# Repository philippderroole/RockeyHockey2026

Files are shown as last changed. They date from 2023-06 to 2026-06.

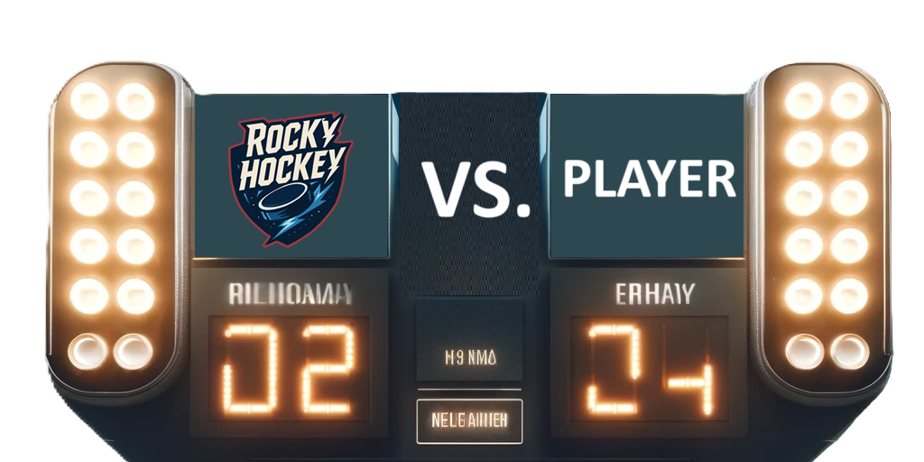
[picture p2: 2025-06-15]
UIServer/resources/imgs/Spielstandanzeige_EM.png

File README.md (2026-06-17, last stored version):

# Rocky-Hockey

## Rust Headless Rewrite

The UI-free Rust controller is available in [rust-controller](rust-controller).

- Entry point: [rust-controller/src/main.rs](rust-controller/src/main.rs)
- Runtime loop: [rust-controller/src/app.rs](rust-controller/src/app.rs)
- Strategy: [rust-controller/src/strategy.rs](rust-controller/src/strategy.rs)
- Camera UDP input: [rust-controller/src/camera.rs](rust-controller/src/camera.rs)
- GRBL stepper output: [rust-controller/src/stepper.rs](rust-controller/src/stepper.rs)

Use [rust-controller/README.md](rust-controller/README.md) for build and run instructions.

## Setup Python venv for VSCode

The file `.vscode/tasks.json` defines a task to set up a python virtual environment (`venv`) in Visual Studio Code. The task can be run by clicking *"Terminal"* -> *"Run Task"* -> *"Build Python Env"*.

- Source for Hockey Image: https://www.svgrepo.com/svg/92168/air-hockey

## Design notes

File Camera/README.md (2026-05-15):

# Rockey Hockey Camera

## Voraussetzungen
- Rust (stable) — Rust und Cargo: https://rustup.rs
- OpenCV und die Entwicklungsheaders
	- Debian: `sudo apt install libopencv-dev pkg-config`
	- macOS: `brew install opencv` (oder über Homebrew-Links)
- Für Cross-Compilation: Docker (nur für das mitgelieferte Script)

## Schnellstart (Entwicklung)

Im Projektordner:

```bash
cargo run -- --web-ui --target-output 0.0.0.0:5005
```

- `--web-ui` startet den integrierten Webserver zur Konfiguration der Detektionsziele.
- `--target-output <ip:port>` bindet eine UDP-Interface, an das sich ein Client mit einem Subscribe-Paket anmelden kann. Danach sendet der Detector die Zielpositionen an diesen Client.

Weitere Optionen sehen Sie mit:

```bash
cargo run -- --help
```

## Cross-Compilation für Raspberry Pi (aarch64)

Das Repository enthält ein Hilfs-Skript zur Cross-Compilation mittels Docker.

1. Stellen Sie sicher, dass Docker installiert und lauffähig ist.
2. Prüfen Sie, dass das Docker-Image im `Dockerfile` mit dem Raspberry Pi kompatibel ist.
3. Führen Sie das Script aus:

```bash
./aarch64-cross.sh
```

Nach erfolgreichem Build liegt die Binary unter:

- `target/aarch64-unknown-linux-gnu/release/rockey_hockey`

Kopieren Sie diese Datei auf Ihr Gerät (z. B. mit `scp`) und führen Sie sie dort aus.

## Konfiguration / Web-UI

Die Web-UI dient zur Auswahl und Feinabstimmung der Detektionsziele. Falls Sie `--web-ui` verwenden, wird ein lokaler Webserver gestartet; die genaue URL wird beim Start geloggt.

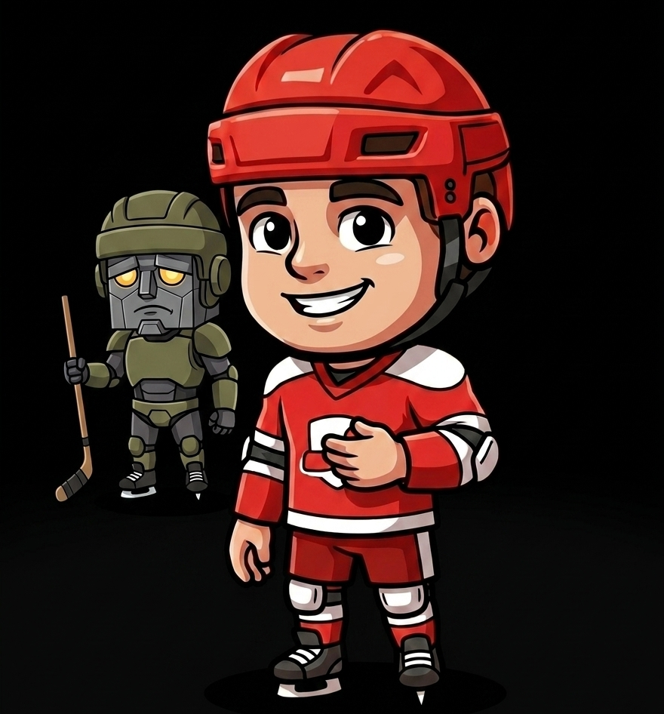
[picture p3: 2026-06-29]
UIServer/resources/imgs/WinningPlayer.png

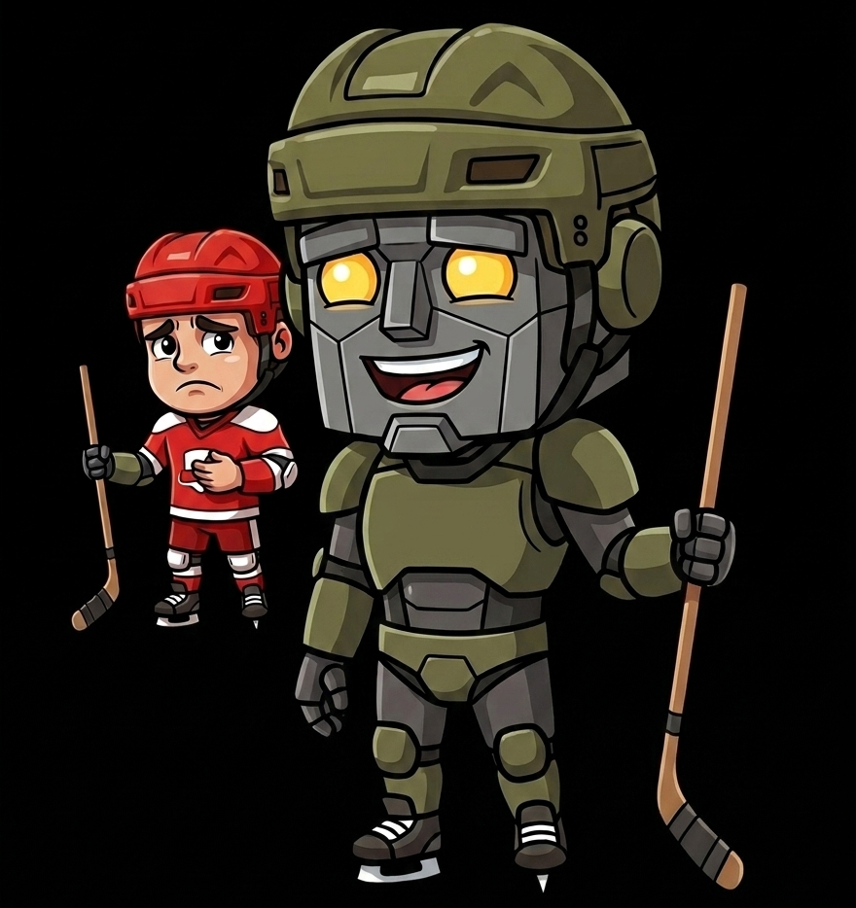
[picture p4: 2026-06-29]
UIServer/resources/imgs/WinningBot.png

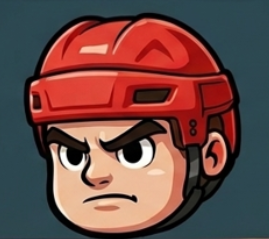
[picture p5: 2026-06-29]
UIServer/resources/imgs/Kopf_des_Spielers.png

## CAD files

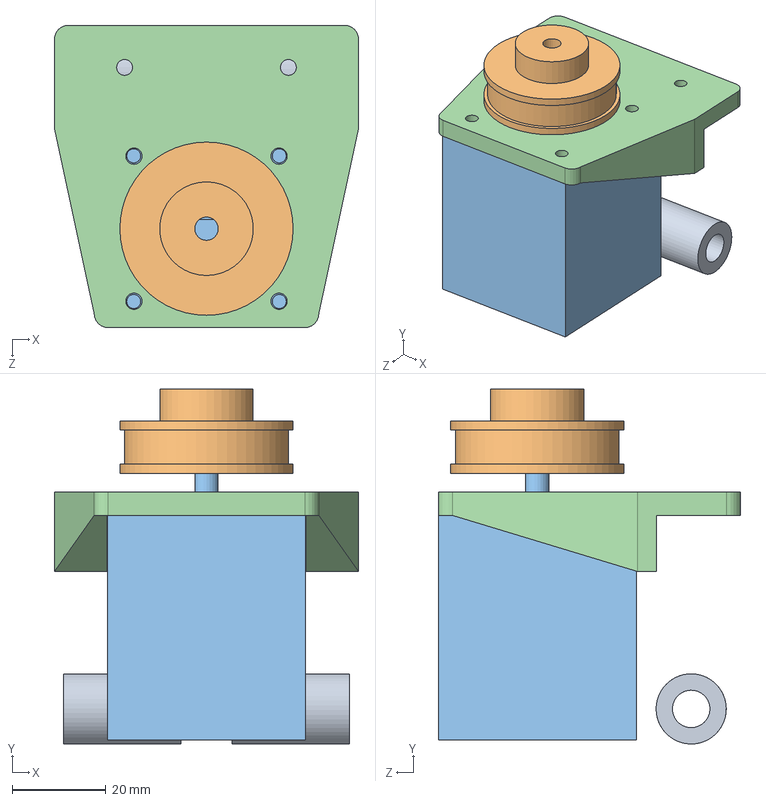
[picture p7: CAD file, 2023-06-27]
CAD/Solidworks/RH_Baugr_Y_Carriage.SLDASM
65.0 x 75.8 x 64.6 mm
RH_Y_Carriage_Motor_Mount
RH_Nema17_Motor
RH_35mm_Riemenscheibe
RH_Bushing_8mm_15mm x 2

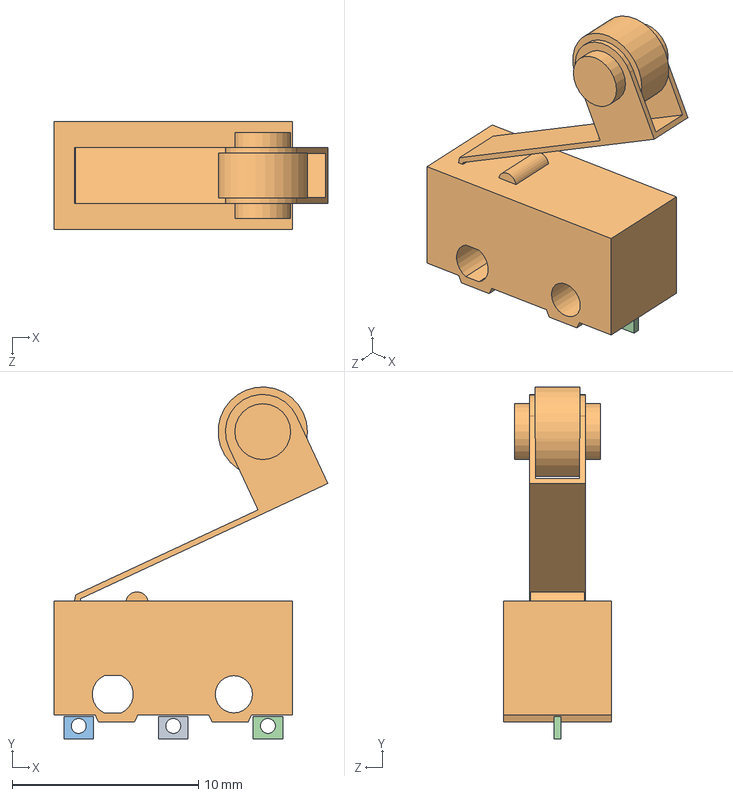
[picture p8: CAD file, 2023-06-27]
CAD/Solidworks/RH_d2f-01fl2-d.SLDASM
14.7 x 18.9 x 5.80 mm
RH_d2f-01fl2-d_01
RH_d2f-01fl2-d_02
RH_d2f-01fl2-d_03
RH_d2f-01fl2-d_04

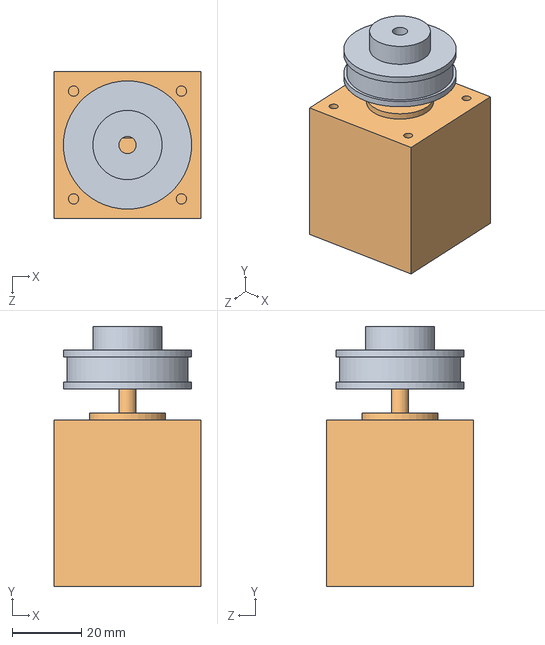
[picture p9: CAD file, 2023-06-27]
CAD/Solidworks/RH_Baugr_Motor_with_90_bracketSLDASM.SLDASM
42.3 x 75.0 x 42.3 mm
RH_Nema17_Motor
RH_35mm_Riemenscheibe

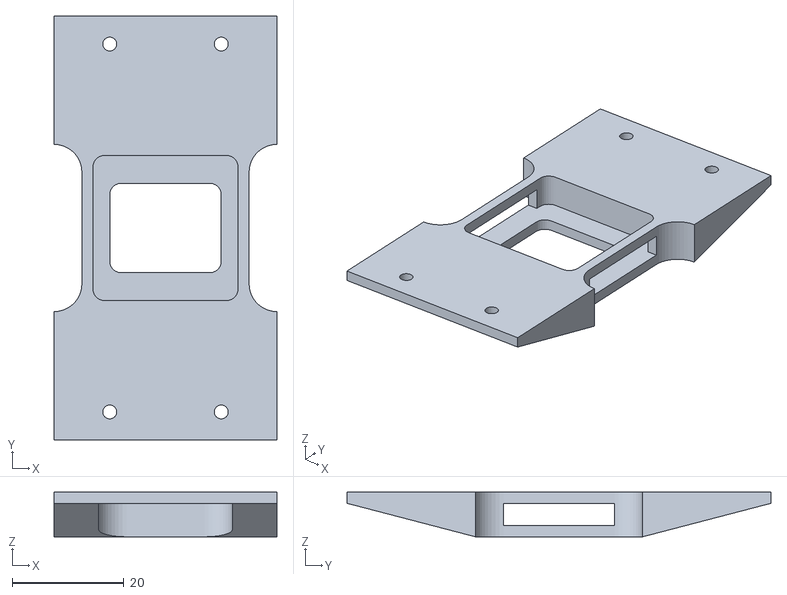
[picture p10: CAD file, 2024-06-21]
CAD/STL/Balken_Halterung_unten.stl
40.0 x 76.0 x 8.00

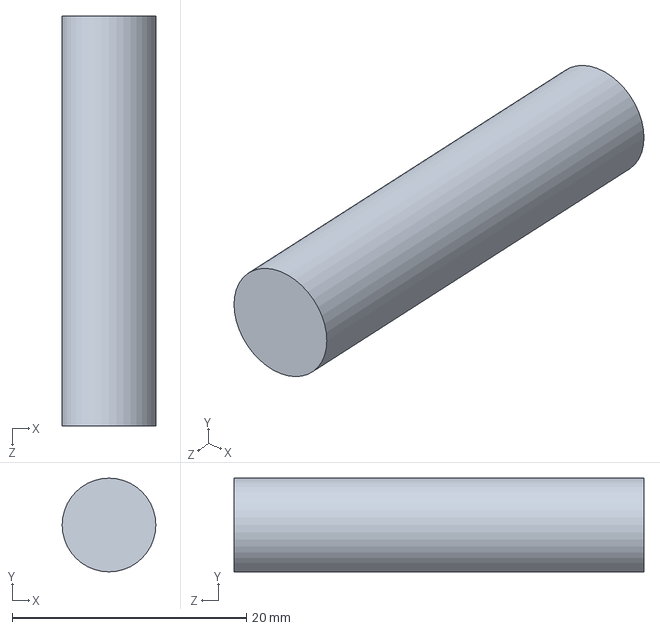
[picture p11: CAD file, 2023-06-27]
CAD/Solidworks/RH_Rail_8mm_35mm.SLDPRT
8.00 x 8.00 x 35.0 mm

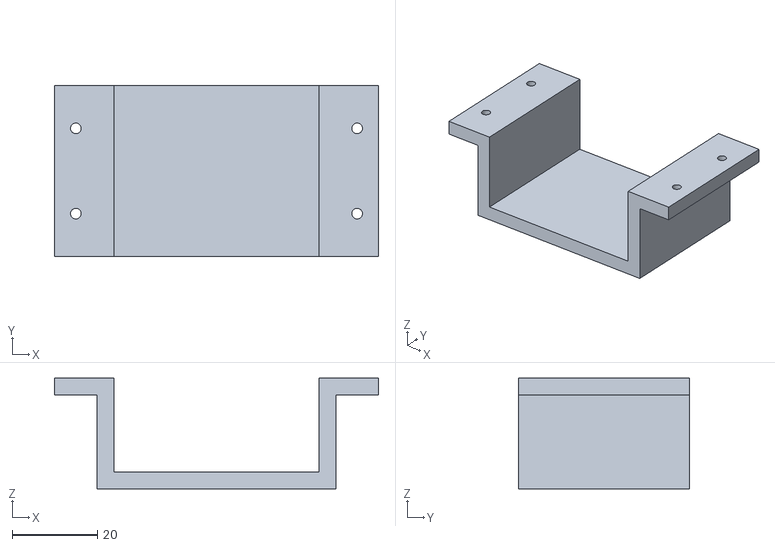
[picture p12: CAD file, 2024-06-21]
CAD/STL/Balken_Halterung_oben.stl
76.0 x 40.0 x 26.0

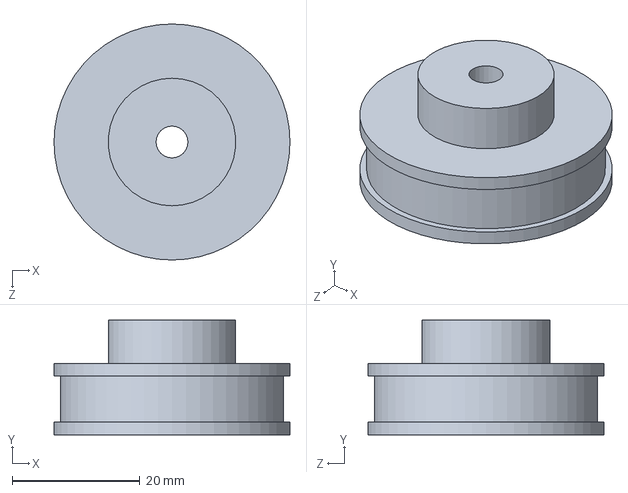
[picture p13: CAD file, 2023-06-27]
CAD/Solidworks/RH_35mm_Riemenscheibe.SLDPRT
37.0 x 18.0 x 37.0 mm

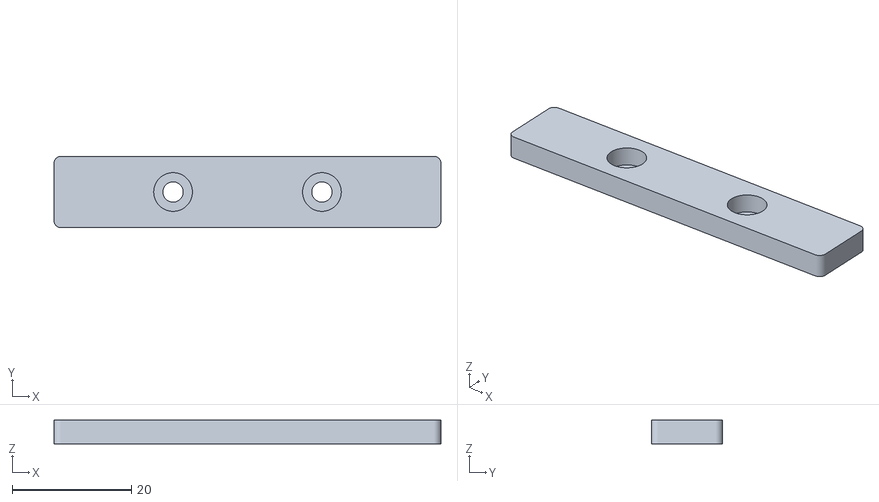
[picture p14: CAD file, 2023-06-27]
CAD/STL/Y_Carriage_Rail_Plate.STL
65.0 x 12.0 x 4.00

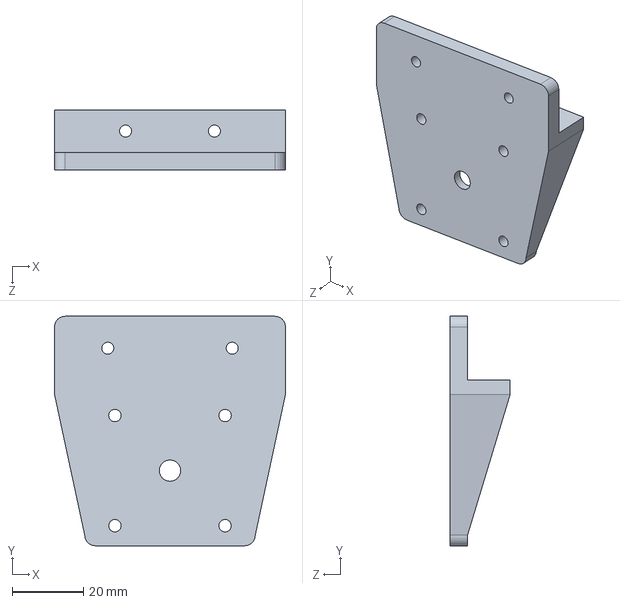
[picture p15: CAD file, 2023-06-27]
CAD/Solidworks/RH_Y_Carriage_Motor_Mount.SLDPRT
65.0 x 64.6 x 17.0 mm

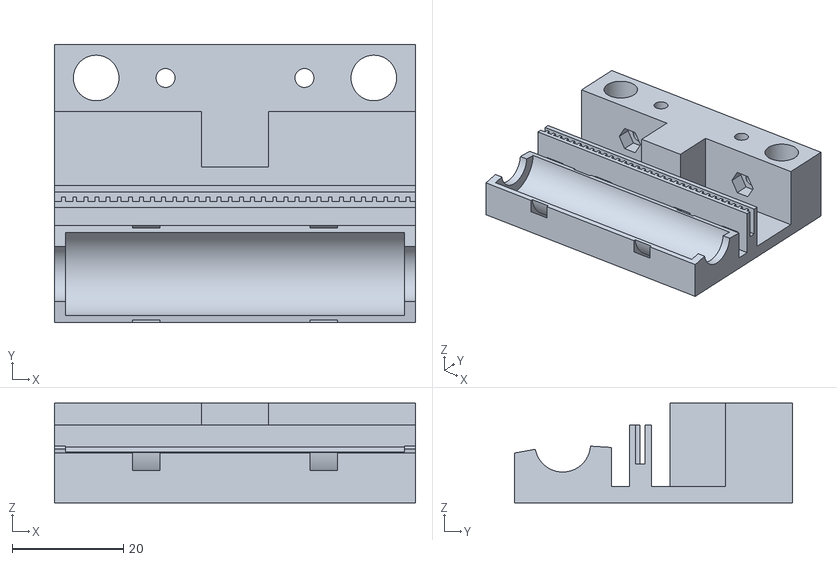
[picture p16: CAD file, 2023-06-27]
CAD/STL/Y_Carriage.STL
65.0 x 50.0 x 18.0

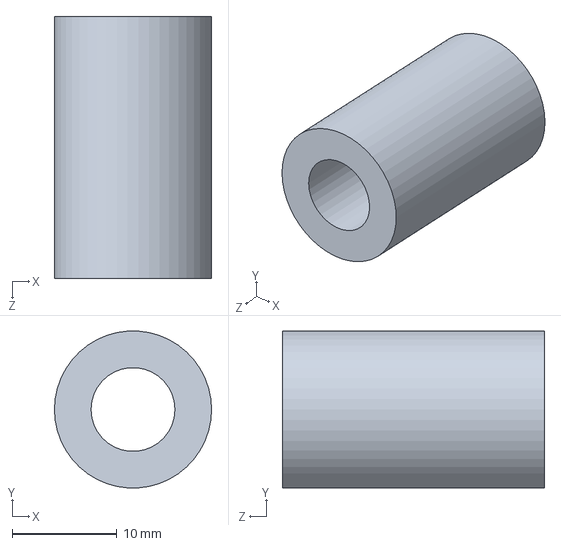
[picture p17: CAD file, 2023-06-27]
CAD/Solidworks/RH_Bushing_8mm_15mm.SLDPRT
15.0 x 15.0 x 25.0 mm

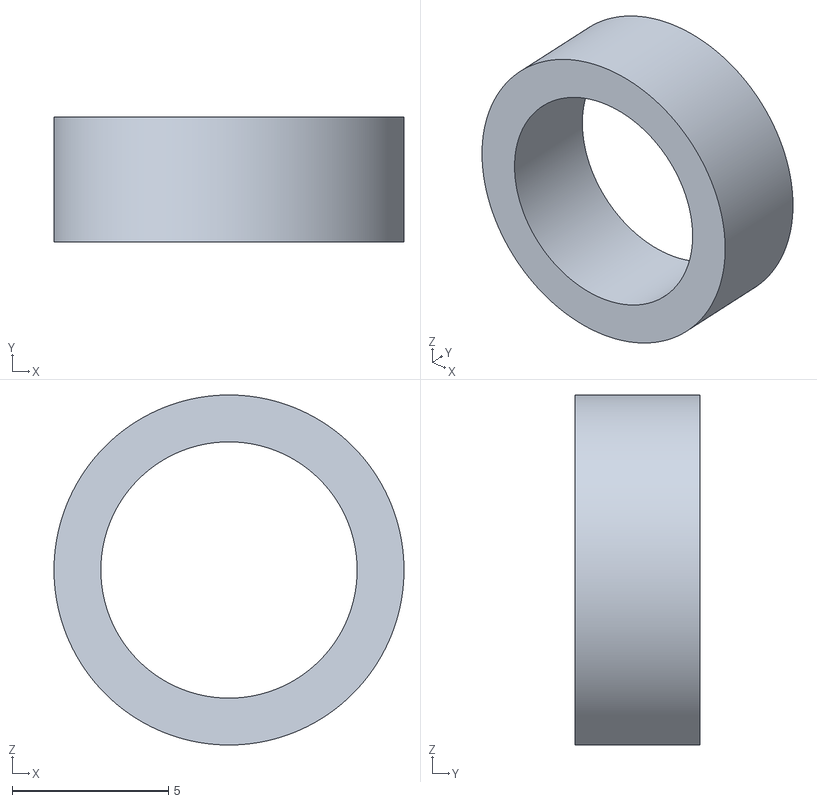
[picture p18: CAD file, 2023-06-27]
CAD/STL/Spacer_4mm.STL
11.2 x 4.00 x 11.2

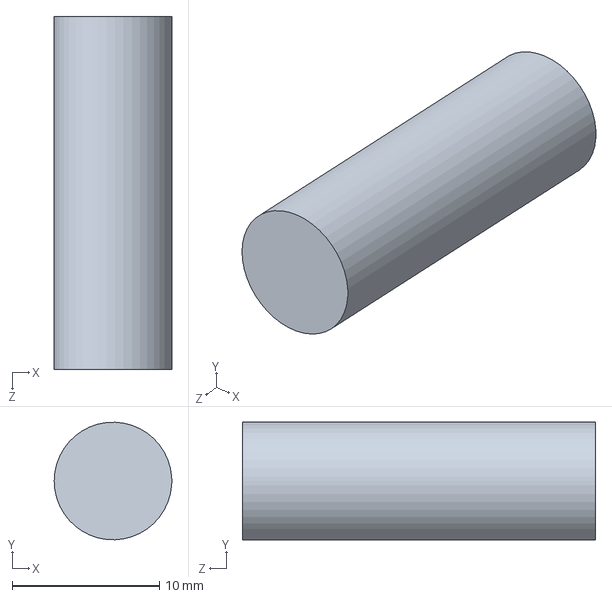
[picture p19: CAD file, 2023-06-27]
CAD/Solidworks/RH_Rail_8mm_24mm.SLDPRT
8.00 x 7.99 x 24.0 mm

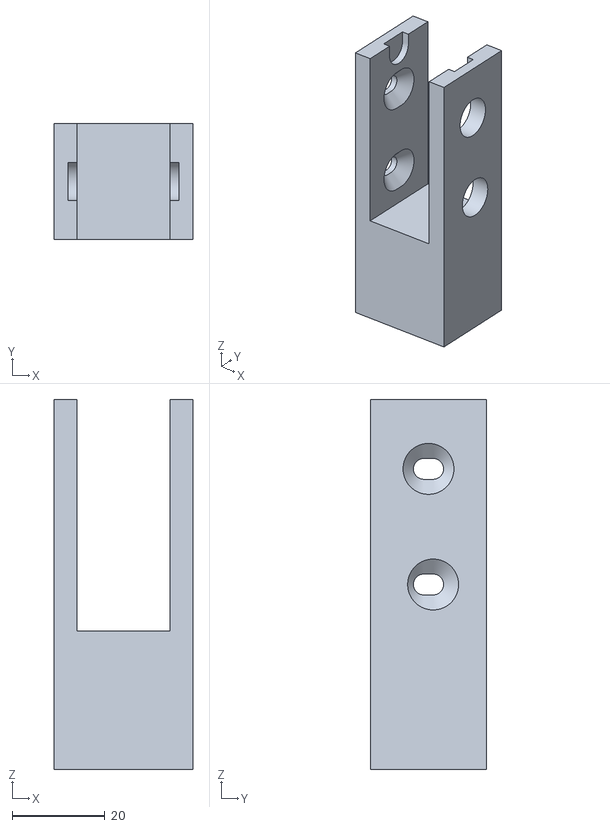
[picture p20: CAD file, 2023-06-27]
CAD/STL/Y_Rail_Stopper_with_Pulley.STL
30.0 x 25.0 x 80.0

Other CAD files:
CAD/Solidworks/RH_Baugr_Pulley_with_Rail_35mm_X_Axis.SLDASM
CAD/Solidworks/RH_Baugr_Pulley_with_Rail_24mm_Y_Axis.SLDASM
CAD/Solidworks/Rocky_Hockey_Full_Assembly.SLDASM
CAD/Solidworks/RH_Nema17_Motor.SLDPRT
CAD/STL/Pulley_36mm_608_GT2_6mm.STL
CAD/STL/Pulley_42_Teeth_GT2_6mm.STL
CAD/STL/Pulley_48_Teeth_GT2_6mm.STL
CAD/STL/Spacer_6_5mm.STL
CAD/STL/X_Carriage_Bushings.STL
CAD/STL/Y_Carriage_Motor_Mount.STL
CAD/STL/Y_Rail_Stopper.STL
CAD/Solidworks/RH_Nema17_Mount.SLDPRT
CAD/Solidworks/RH_Pulley_36mm_608_GT2_6mm.SLDPRT
CAD/Solidworks/RH_Rail_8mm_770mm.SLDPRT
CAD/Solidworks/RH_Rail_8mm_944_85mm.SLDPRT
CAD/Solidworks/RH_Rail_Stopper.SLDPRT
CAD/Solidworks/RH_Rail_Stopper_with_Pulley.SLDPRT
CAD/Solidworks/RH_Spacer_4mm.SLDPRT
CAD/Solidworks/RH_Spacer_6_5mm.SLDPRT
CAD/Solidworks/RH_Tisch.SLDPRT
CAD/Solidworks/RH_X_Carriage_Bushings.SLDPRT
CAD/Solidworks/RH_Y_Carriage.SLDPRT
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

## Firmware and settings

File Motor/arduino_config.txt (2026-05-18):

$0 = 10    (Step pulse time, microseconds)
$1 = 25    (Step idle delay, milliseconds)
$2 = 0    (Step pulse invert, mask)
$3 = 3    (Step direction invert, mask)
$4 = 0    (Invert step enable pin, boolean)
$5 = 0    (Invert limit pins, boolean)
$6 = 0    (Invert probe pin, boolean)
$10 = 1    (Status report options, mask)
$11 = 0.010    (Junction deviation, millimeters)
$12 = 0.002    (Arc tolerance, millimeters)
$13 = 0    (Report in inches, boolean)
$20 = 1    (Soft limits enable, boolean)
$21 = 0    (Hard limits enable, boolean)
$22 = 1    (Homing cycle enable, boolean)
$23 = 3    (Homing direction invert, mask)
$24 = 25.000    (Homing locate feed rate, mm/min)
$25 = 3000.000    (Homing search seek rate, mm/min)
$26 = 250    (Homing switch debounce delay, milliseconds)
$27 = 1.500    (Homing switch pull-off distance, millimeters)
$30 = 1000    (Maximum spindle speed, RPM)
$31 = 0    (Minimum spindle speed, RPM)
$32 = 0    (Laser-mode enable, boolean)
$100 = 20.000    (X-axis travel resolution, step/mm)
$101 = 20.000    (Y-axis travel resolution, step/mm)
$102 = 250.000    (Z-axis travel resolution, step/mm)
$110 = 50000.000    (X-axis maximum rate, mm/min)
$111 = 50000.000    (Y-axis maximum rate, mm/min)
$112 = 2000.000    (Z-axis maximum rate, mm/min)
$120 = 6000.000    (X-axis acceleration, mm/sec^2)
$121 = 6000.000    (Y-axis acceleration, mm/sec^2)
$122 = 10.000    (Z-axis acceleration, mm/sec^2)
$130 = 350.000    (X-axis maximum travel, millimeters)
$131 = 360.000    (Y-axis maximum travel, millimeters)
$132 = 200.000    (Z-axis maximum travel, millimeters)

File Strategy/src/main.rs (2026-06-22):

extern crate piston_window;

use std::sync::mpsc::{Receiver, TryRecvError};

use crate::{
    camera::{Detection, DetectionTarget, spawn_camera_listener},
    commands::Command,
    config::{
        BOARD_HEIGHT, BOARD_WIDTH, DEFAULT_CAMERA_HOST, DEFAULT_CAMERA_PORT,
        DEFAULT_STEPPER_BAUDRATE, DEFAULT_STEPPER_PORT, GOAL_Y_MAX, GOAL_Y_MIN, PUCK_RADIUS,
        SIMULATOR_BORDER, WINDOW_HEIGHT, WINDOW_WIDTH,
    },
    motor_controls::{DryRunStepper, GrblStepper, StepperHandle, spawn_stepper_worker},
    puck::Puck,
};
use clap::Parser;
use nalgebra::{Point2, distance};
use piston_window::{texture::TextureSettings, *};

mod camera;
mod commands;
mod config;
mod motor_controls;
mod puck;
mod simulation;
mod strategy;

const VELOCITY_DRAW_SCALE: f64 = 6.0;

#[derive(Debug, Parser)]
#[command(author, version, about = "Fast headless Rocky Hockey controller")]
struct Cli {
    #[arg(long, default_value = DEFAULT_CAMERA_HOST)]
    camera_host: String,
    #[arg(long, default_value_t = DEFAULT_CAMERA_PORT)]
    camera_port: u16,
    #[arg(long, default_value = DEFAULT_STEPPER_PORT)]
    stepper_port: String,
    #[arg(long, default_value_t = DEFAULT_STEPPER_BAUDRATE)]
    stepper_baudrate: u32,
    #[arg(long, default_value_t = false)]
    dry_run: bool,
}

fn main() -> anyhow::Result<()> {
    let cli = Cli::parse();

    let mut stepper = if cli.dry_run {
        spawn_stepper_worker(Box::new(DryRunStepper::new()))?
    } else {
        spawn_stepper_worker(Box::new(GrblStepper::connect(
            &cli.stepper_port,
            cli.stepper_baudrate,
        )?))?
    };

    stepper.calibrate()?;

    let rx = spawn_camera_listener(&cli.camera_host, cli.camera_port)?;
    let mut board = Board::new(rx, stepper)?;
    board.run()?;

    Ok(())
}

struct Board {
    robot_current_position: Point2<f64>,
    robot_target_position: Point2<f64>,
    last_commanded_target: Option<Point2<f64>>,
    puck: Puck,
    predicted_puck_path: Vec<Point2<f64>>,
    rx: Receiver<Vec<Detection>>,
    cursor_position: Point2<f64>,
    velocity_drag_start: Option<Point2<f64>>,
    stepper: StepperHandle,
    current_command: Option<Command>,
}

impl Board {
    pub fn new(rx: Receiver<Vec<Detection>>, stepper: StepperHandle) -> anyhow::Result<Self> {
        Ok(Board {
            robot_current_position: Point2::new(100.0, 200.0),
            robot_target_position: Point2::new(100.0, 200.0),
            last_commanded_target: None,
            puck: Puck::new(),
            predicted_puck_path: Vec::new(),
            rx,
            cursor_position: Point2::new(0.0, 0.0),
            velocity_drag_start: None,
            stepper,
            current_command: None,
        })
    }

    pub fn run(&mut self) -> anyhow::Result<()> {
        let mut window: PistonWindow =
            WindowSettings::new("Rockey Hockey 2026", [WINDOW_HEIGHT, WINDOW_WIDTH])
                .exit_on_esc(true)
                .build()
                .map_err(|e| anyhow::anyhow!("failed to create window: {e}"))?;

        let mut glyphs = Glyphs::new(
            "./assets/FiraSans-Regular.ttf",
            window.create_texture_context(),
            TextureSettings::new(),
        )?;

        let mut events = Events::new(EventSettings::new().ups(60).max_fps(60));
        while let Some(e) = events.next(&mut window) {
            self.update(&e)?;
            if e.render_args().is_some() {
                self.draw(&e, &mut window, &mut glyphs)?;
            }
        }

        Ok(())
    }

    pub fn update(&mut self, e: &Event) -> anyhow::Result<()> {
        e.mouse_cursor(|pos| {
            self.cursor_position = Point2::new(pos[0], pos[1]);
        });

        if let Some(Button::Mouse(MouseButton::Left)) = e.press_args() {
            self.puck.set_position(Point2::new(
                self.cursor_position[0] - SIMULATOR_BORDER,
                self.cursor_position[1] - SIMULATOR_BORDER,
            ));
        }

        if let Some(Button::Mouse(MouseButton::Right)) = e.press_args() {
            self.velocity_drag_start = Some(self.cursor_position);
        }

        if let Some(Button::Mouse(MouseButton::Right)) = e.release_args()
            && let Some(start_position) = self.velocity_drag_start.take()
        {
            let velocity = (self.cursor_position - start_position) * VELOCITY_DRAW_SCALE;
            if velocity.magnitude() > f64::EPSILON {
                self.puck.set_velocity(velocity);
            }
        }

        if e.update_args().is_none() {
            return Ok(());
        }

        let mut latest_detections = None;
        loop {
            match self.rx.try_recv() {
                Ok(detections) => {
                    latest_detections = Some(detections);
                }
                Err(TryRecvError::Empty) => break,
                Err(TryRecvError::Disconnected) => {
                    anyhow::bail!("camera channel disconnected");
                }
            }
        }

        if let Some(detections) = latest_detections {
            for detection in detections {
                match detection.target {
                    DetectionTarget::Puck => {
                        self.puck.update(detection.position, detection.timestamp);
                    }
                    DetectionTarget::Robot => {
                        self.robot_current_position = detection.position;
                    }
                    DetectionTarget::Unknown => {}
                }
            }
        }

        let (next_move, predicted_puck_path) =
            strategy::get_next_move(self.robot_current_position, &self.puck);
        self.predicted_puck_path = predicted_puck_path;

        if let Some(next_move) = next_move {
            self.execute(next_move)?;
        } else {
            self.last_commanded_target = None;
        }

        Ok(())
    }

    pub fn draw(
        &mut self,
        e: &Event,
        window: &mut PistonWindow,
        glyphs: &mut Glyphs,
    ) -> anyhow::Result<()> {
        window.draw_2d(e, |c, g, _| {
            use graphics::*;

            clear([0.5, 0.5, 0.5, 1.0], g);

            // Border
            Rectangle::new([0.0, 0.0, 0.0, 1.0]).draw(
                [
                    0.0,
                    0.0,
                    BOARD_HEIGHT + SIMULATOR_BORDER * 2.0,
                    BOARD_WIDTH + SIMULATOR_BORDER * 2.0,
                ],
                &c.draw_state,
                c.transform,
                g,
            );

            // Playable board
            Rectangle::new([0.8, 0.8, 0.8, 1.0]).draw(
                [0.0, 0.0, BOARD_HEIGHT, BOARD_WIDTH],
                &c.draw_state,
                c.transform.trans(SIMULATOR_BORDER, SIMULATOR_BORDER),
                g,
            );

            // Goal
            Rectangle::new([1.0, 0.0, 0.0, 1.0]).draw(
                [0.0, GOAL_Y_MIN, SIMULATOR_BORDER, GOAL_Y_MAX - GOAL_Y_MIN],
                &c.draw_state,
                c.transform,
                g,
            );

            Ellipse::new([1.0, 0.0, 0.0, 1.0]).draw(
                [
                    self.robot_target_position.x - 20.0,
                    self.robot_target_position.y - 20.0,
                    40.0,
                    40.0,
                ],
                &c.draw_state,
                c.transform.trans(SIMULATOR_BORDER, SIMULATOR_BORDER),
                g,
            );

            Ellipse::new([0.0, 1.0, 0.0, 1.0]).draw(
                [
                    self.robot_current_position.x - 20.0,
                    self.robot_current_position.y - 20.0,
                    40.0,
                    40.0,
                ],
                &c.draw_state,
                c.transform.trans(SIMULATOR_BORDER, SIMULATOR_BORDER),
                g,
            );

            Ellipse::new([0.0, 0.0, 1.0, 1.0]).draw(
                [
                    self.puck.x() - PUCK_RADIUS,
                    self.puck.y() - PUCK_RADIUS,
                    PUCK_RADIUS * 2.0,
                    PUCK_RADIUS * 2.0,
                ],
                &c.draw_state,
                c.transform.trans(SIMULATOR_BORDER, SIMULATOR_BORDER),
                g,
            );

            // Attack line
            Line::new([0.0, 0.0, 0.0, 1.0], 2.0).draw(
                [300.0, 0.0, 300.0, BOARD_WIDTH],
                &c.draw_state,
                c.transform.trans(SIMULATOR_BORDER, SIMULATOR_BORDER),
                g,
            );

            if let Some(start_position) = self.velocity_drag_start {
                Line::new([0.2, 0.2, 0.9, 1.0], 2.0).draw(
                    [
                        start_position.x,
                        start_position.y,
                        self.cursor_position.x,
                        self.cursor_position.y,
                    ],
                    &c.draw_state,
                    c.transform,
                    g,
                );
            }

            for segment in self.predicted_puck_path.windows(2) {
                let start = segment[0];
                let end = segment[1];
                Line::new([0.8, 0.0, 0.8, 1.0], 2.0).draw(
                    [start.x, start.y, end.x, end.y],
                    &c.draw_state,
                    c.transform.trans(SIMULATOR_BORDER, SIMULATOR_BORDER),
                    g,
                );
            }

            Text::new_color([1.0, 1.0, 0.0, 1.0], 32)
                .draw(
                    format!(
                        "Robot target: ({:.1}, {:.1})",
                        self.robot_target_position.x, self.robot_target_position.y
                    )
                    .as_str(),
                    glyphs,
                    &c.draw_state,
                    c.transform
                        .trans(20.0, BOARD_WIDTH + SIMULATOR_BORDER + 40.0),
                    g,
                )
                .unwrap();
        });

        Ok(())
    }

    fn execute(&mut self, command: Command) -> Result<(), anyhow::Error> {
        self.robot_target_position = command.get_target_position();

        if self
            .current_command
            .as_ref()
            .map(|c| distance(&c.get_target_position(), &command.get_target_position()) < 30.0)
            .unwrap_or(false)
        {
            return Ok(());
        }

        self.current_command = Some(command.clone());
        let command = match command {
            Command::MoveTo(position) => Command::Defend(map_to_motor_coordinates(position)),
            Command::Shoot { staging, target } => Command::Shoot {
                staging: map_to_motor_coordinates(staging),
                target: map_to_motor_coordinates(target),
            },
            Command::Defend(position) => Command::Defend(map_to_motor_coordinates(position)),
            Command::Calibrate(response_tx) => Command::Calibrate(response_tx),
        };

        self.stepper.execute(command);

        Ok(())
    }
}

fn map_to_motor_coordinates(position: Point2<f64>) -> Point2<f64> {
    Point2::new(
        (position.x - 2.0) * 138.0 / 106.0,
        (position.y - 2.0) * 330.0 / 306.0,
    )
}

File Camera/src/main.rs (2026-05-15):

use clap::Parser;
use std::net::SocketAddr;

use app::input_modes::InputSource;

mod app;

#[derive(Parser, Debug)]
#[command(name = "RockeyHockey")]
#[command(about = "Puck detection system for hockey", long_about = None)]
struct Args {
    /// Optional path to a recorded video file instead of webcam input
    #[arg(long)]
    video: Option<String>,
    /// Optional flag to use the Raspberry Pi camera instead of a webcam
    #[arg(long)]
    pi_camera: bool,
    /// Enable browser-based live settings editor at http://0.0.0.0:<web_ui_port>
    #[arg(long)]
    web_ui: bool,
    /// Port for browser-based live settings editor
    #[arg(long, default_value_t = 8080)]
    web_ui_port: u16,
    /// Optional UDP interface for detected target coordinates, for example 0.0.0.0:5005
    #[arg(long)]
    target_output: Option<SocketAddr>,
}

fn main() -> anyhow::Result<()> {
    env_logger::init();

    let args = Args::parse();
    app::run(app::RunConfig {
        input_source: if let Some(video_path) = args.video {
            InputSource::VideoFile(video_path)
        } else if args.pi_camera {
            InputSource::PiCamera
        } else {
            InputSource::Camera(0)
        },
        web_ui_enabled: args.web_ui,
        web_ui_port: args.web_ui_port,
        target_output: args.target_output,
    })
}

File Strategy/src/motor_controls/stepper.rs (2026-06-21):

use std::io::{ErrorKind, Write};
use std::thread;
use std::time::{Duration, Instant};

use anyhow::{Context, Result};
use nalgebra::{Point2, distance};
use serialport::SerialPort;

use crate::config::{ROBOT_MAX_X, ROBOT_MAX_Y, ROBOT_TARGET_OFFSET};
use crate::motor_controls::Stepper;

pub struct DryRunStepper {
    target_position: Point2<f64>,
}

impl DryRunStepper {
    pub fn new() -> Self {
        Self {
            target_position: Point2::new(0.0, 0.0),
        }
    }
}

impl Stepper for DryRunStepper {
    fn calibrate(&mut self) -> Result<()> {
        println!("[dry-run] calibrate");
        Ok(())
    }

    fn move_to_position(&mut self, position: Point2<f64>, _feedrate: u32) -> Result<()> {
        let position = Point2::new(
            position.x - ROBOT_TARGET_OFFSET,
            position.y - ROBOT_TARGET_OFFSET,
        );

        if distance(&self.target_position, &position) < 30.0 {
            return Ok(());
        }

        println!(
            "[dry-run] move to ({:.1}, {:.1}) from ({:.1}, {:.1})",
            position.x, position.y, self.target_position.x, self.target_position.y
        );

        self.target_position = position;
        Ok(())
    }
}

pub struct GrblStepper {
    connection: Box<dyn SerialPort>,
    target_position: Point2<f64>,
}

impl GrblStepper {
    pub fn connect(port: &str, baudrate: u32) -> Result<Self> {
        let mut connection = serialport::new(port, baudrate)
            .timeout(Duration::from_millis(1000))
            .open()
            .with_context(|| format!("open serial port {port} @ {baudrate}"))?;

        connection.write_all(b"\r\n\r\n").context("wake up GRBL")?;
        thread::sleep(Duration::from_millis(2000));

        let mut stepper = Self {
            connection,
            target_position: Point2::new(0.0, 0.0),
        };
        let _ = stepper.send_command("$X")?;
        Ok(stepper)
    }

    fn send_command(&mut self, command: &str) -> Result<String> {
        let payload = format!("{command}\n");
        self.connection
            .write_all(payload.as_bytes())
            .with_context(|| format!("write command: {command}"))?;

        let start = Instant::now();
        let timeout = Duration::from_millis(2000);
        let mut line_buf = Vec::<u8>::with_capacity(128);

        while start.elapsed() < timeout {
            line_buf.clear();
            if read_line(&mut *self.connection, &mut line_buf)? {
                let response = trim_ascii_whitespace(&line_buf);
                if response == b"ok" || response.starts_with(b"error") {
                    return Ok(String::from_utf8_lossy(response).to_string());
                }
            } else {
                thread::sleep(Duration::from_millis(2));
            }
        }

        Ok("TIMEOUT".to_string())
    }

    fn wait_for_idle(&mut self, timeout: Duration, recover_alarm: bool) -> Result<()> {
        let start = Instant::now();
        let mut line_buf = Vec::<u8>::with_capacity(128);

        while start.elapsed() < timeout {
            self.connection
                .write_all(b"?")
                .context("query GRBL status")?;

            line_buf.clear();
            if read_line(&mut *self.connection, &mut line_buf)? {
                let response = trim_ascii_whitespace(&line_buf);
                if response.starts_with(b"<Idle") {
                    return Ok(());
                }
                if response.starts_with(b"<Alarm") {
                    let alarm = String::from_utf8_lossy(response).to_string();
                    if recover_alarm {
                        eprintln!("GRBL alarm during homing, trying unlock: {alarm}");
                        let unlock = self.send_command("$X")?;
                        if unlock.starts_with("error") {
                            anyhow::bail!(
                                "GRBL alarm recovery failed while unlocking after homing: {unlock}"
                            );
                        }
                        thread::sleep(Duration::from_millis(50));
                        continue;
                    }

                    anyhow::bail!("GRBL entered alarm state: {alarm}");
                }
            }

            thread::sleep(Duration::from_millis(10));
        }

        anyhow::bail!("timeout waiting for GRBL idle state");
    }
}

impl Stepper for GrblStepper {
    fn calibrate(&mut self) -> Result<()> {
        let response = self.send_command("$H")?;
        if response.starts_with("error") {
            anyhow::bail!("GRBL homing error: {response}");
        }
        self.wait_for_idle(Duration::from_secs(20), true)?;

        let unlock = self.send_command("$X")?;
        if unlock.starts_with("error") {
            anyhow::bail!("GRBL unlock error after homing: {unlock}");
        }
        Ok(())
    }

    fn move_to_position(&mut self, position: Point2<f64>, feedrate: u32) -> Result<()> {
        let position = Point2::new(
            position.x - ROBOT_TARGET_OFFSET,
            position.y - ROBOT_TARGET_OFFSET,
        );

        if distance(&self.target_position, &position) < 30.0 {
            return Ok(());
        }

        /*println!(
            "target position: ({x:.1}, {y:.1}), current position: ({:.1}, {:.1})",
            self.target_position.x, self.target_position.y
        );
        println!(
            "distance to target: {:.1}",
            distance(&self.target_position, &position)
        );
        println!("moving to ({x:.1}, {y:.1})");*/

        let x = position.x.clamp(0.0, ROBOT_MAX_X);
        let y = position.y.clamp(0.0, ROBOT_MAX_Y);

        self.target_position = position;
        let cmd = format!("$J=G21G90X{:.2}Y{:.2}F{}", x, y, feedrate.max(1));
        let response = self.send_command(&cmd)?;
        if response.starts_with("error") {
            anyhow::bail!("GRBL error on move command: {response}");
        }
        Ok(())
    }
}

fn trim_ascii_whitespace(bytes: &[u8]) -> &[u8] {
    let mut start = 0;
    let mut end = bytes.len();

    while start < end && bytes[start].is_ascii_whitespace() {
        start += 1;
    }

    while end > start && bytes[end - 1].is_ascii_whitespace() {
        end -= 1;
    }

    &bytes[start..end]
}

fn read_line(port: &mut dyn SerialPort, out: &mut Vec<u8>) -> Result<bool> {
    let mut byte = [0_u8; 1];
    loop {
        match port.read(&mut byte) {
            Ok(0) => return Ok(false),
            Ok(1) => {
                out.push(byte[0]);
                if byte[0] == b'\n' {
                    return Ok(true);
                }
            }
            Ok(_) => {}
            Err(err) if err.kind() == ErrorKind::TimedOut => return Ok(false),
            Err(err) => return Err(err).context("read serial response"),
        }
    }
}

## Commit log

2023-03-27 moved eol files and created new dir for arduino stuff
2023-04-03 added StepperController.py
2023-04-06 added Camera Class
2023-04-17 - Added gitignore - Added pysimplegui to requirements.txt - Added first prototype of UI.
2023-05-01 Refactored image filtering.
2023-05-08 FIrst working prototype (kinda).
2023-05-15 Added position buffer to make it less "jittery".
2023-06-12 Added frametime and fps counter.
2023-06-12 Improved camera fps to 30 on windows.
2023-06-15 may improved camera more at least on mac os
2023-06-16 switched from timer to thread
2023-06-26 improved camera class
2023-06-27 added Solidworks and STL files
    [Pulley_36mm_608_GT2_6mm.STL, Pulley_42_Teeth_GT2_6mm.STL, Pulley_48_Teeth_GT2_6mm.STL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]
2024-04-09 Fix timeRemaining formula
2024-04-20 test new puck detection, change camera feed to stream
2024-04-23 Camera Detection changes
2024-05-09 Added sounds and timer
2024-05-13 Add experimental ws2812b led strip support
2024-05-14 revert threading
2024-05-14 fix camera
2024-05-28 clean up frame processing code
2024-06-04 remove robotdetection skip print
2024-06-11 Adjust LED animation speed
2024-06-16 Changes: - Die Seiten Abstände in den der Roboter nicht machen soll bzw. nicht hin fahren soll ist größer - zudem fährt er nur nach vorne wenn die Puck geschwindigkeit gering genug ist das der Puck g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
    ps:
    sorry für die komische syntax keine ahnung was da bei mit passiert ist
2024-06-17 wieder lesbar und Konstanten GoRight GOLEFT geändert
2024-06-17 Change button ids
2025-04-10 Add basic virtual camera functionality
    Implemented an option to use a pre-recorded video as input instead of the physical camera.
    This allows the program to run and be tested without needing to connect to the real camera at the hockey table.
    Change the URL in constants.py to "virtual" to use the virtual camera.
    The current video might not be perfect (slightly wrong fps and compressed) but should be good enough for now.
2025-06-02 only print if values actually get send
2025-06-05 Refactor code
    Changed the name of "InitializeCamera" to "apply_perspective_correction". Because Camera isnt initialized here.
    Also changed where the frame gets read from the camera class. Now the update method reads the frame and then pushes it through the apply_perspective_correction method.
    Should be the same behaviour as before but looks cleaner in my opinion
2025-06-05 Fix bug
    With the previous change to where the frame gets read by the update method, this would throw an exception. Also this is propably not needed because the frame gets updated constantly anyway.
    So i just removed it. Should not affect behaviour.
2025-06-16 ignore response and fix false state print
    [StepperController.py]
2025-06-16 Auflösung der Videos war zu hoch. Konvertierung zu kleinerem Format. Skriptänderung für das Einfügen der loadingAnimation
2025-06-20 Neue Animationen, die bei Start und Stop wechseln
2025-06-21 sync position only when stuck
    [StepperController.py]
2026-04-12 feat: Modified StepperController.py to be compatible with grbl firmware for testing purposes.
2026-04-14 fix: blocking issue removed
    [StepperController.py, test.py]
2026-04-20 camera rewrite
2026-04-20 Switched error handling from opencv to anyhow
    [main.rs]
2026-04-27 feat: Update jog command format and enhance test coverage for StepperController
2026-05-11 fix: absolute mode, updated boundaries
    [StepperController.py]
2026-05-11 fix: removed Constants import from StepperController
    [StepperController.py]
2026-05-18 feat: update position constants and enhance StepperController functionality with new commands and tests
    [arduino_config.txt]
2026-05-19 refactor: fix GRBL 1.1 communication stability, startup hangs, and jog races
    [StepperController.py, test.py]
2026-05-21 fix: unlocks controller after calibrate, timeout error msg while calibrating, add worker test
    - StepperController.calibrate() now sends an unlock command after
    calibrating, in case of alarm state
    - added test for move worker
    - send command timeout is 2 secs, homing often takes longer than 2 secs.
    bypassed send command when sending homing command
    [StepperController.py, test_worker.py]
2026-06-10 fixed homing state
2026-06-12 homing state fix v2
2026-06-19 feat: initialize Strategy project with camera detection and motor control
    - Add Cargo.toml with dependencies for the project.
    - Implement camera listener for UDP detection of puck and robot positions.
    - Create configuration constants for board dimensions and camera settings.
    - Develop main application logic to handle camera input and control motors.
    - Introduce motor control abstractions for dry run and GRBL stepper implementations.
    - Implement puck simulation and path prediction based on detected positions.
2026-06-21 Implement strategy for robot puck movement and goal blocking
    - Added `get_next_move` function to determine the robot's next move based on puck position and velocity.
    - Introduced helper functions for goal blocking, attacking, and repositioning the robot.
    - Implemented logic for handling puck at the left border and determining safe bounce points.
    - Added tests for puck behavior at the left border and attack target overshooting.
    [main.rs, stepper.rs, worker_thread.rs]
